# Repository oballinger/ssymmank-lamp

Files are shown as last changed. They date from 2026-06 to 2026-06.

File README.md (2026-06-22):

# Ssymmank lamp

Geometry and 3D-printable parts for the Günter Ssymmank Philharmonie lamp.

The lamp is a **spherical tessellation of regular pentagons, squares and
triangles** — i.e. the **rhombicosidodecahedron** (an Archimedean solid):

| | count |
|---|---|
| pentagons | 12 |
| squares | 30 |
| triangles | 20 |
| vertices | 60 |
| edges | 120 |
| faces | 62 |

Vertex configuration is `3.4.5.4` (triangle, square, pentagon, square meet at
every vertex).

Source / reference exhibition:
https://blog.sbb.berlin/darunter-sieht-man-gut-aus-ausstellung-zu-den-leuchten-guenter-ssymmanks-eroeffnet/

## Layout

Everything is organised **by component**. Each component has its generator code
under `src/<component>/` and its OpenSCAD models under `models/<component>/`.

```
src/
  core/        shared library — the solid's geometry + transform math (imported, not run)
  frame/       build_star.py (printable star/connector decomposition)
  assembly/    build_assembly.py (frame + all 72 mushrooms)
  mockups/     build_mockups.py (the images/ PNG mockups)
models/
  frame/       star · connector · stars_assembly · mate_test · test_edges · stem_fit
    renders/   transient previews / STL exports for the frame (git-ignored)
  mushrooms/   mushroom (+ simple, small/medium/large/xl, small_curved) — hand-written
    renders/   transient previews / STL exports for the mushrooms (git-ignored)
  assembly/    assembly.scad
    renders/   transient previews / STL exports for the assembly (git-ignored)
images/        reference renders (committed)
```

Generators bake all orientation maths (4×4 `multmatrix` transforms) into the
`.scad`, so each `.scad` is just data + tiny modules. The `assembly.scad`
pulls the frame from `../frame/` and the mushroom core from `../mushrooms/`.

### `src/core/` — shared library
| file | what |
|---|---|
| `geometry.py` | single source of truth — vertices, edges, faces of the solid |
| `transforms.py` | the transform helpers (`bar_transforms`, `node_transforms`, …) shared by every generator |

### `src/frame/` → `models/frame/`
| file | what |
|---|---|
| `build_star.py` → `star.scad` + … | the **printable decomposition** (below). `star.scad` is the shared library every other frame model `include`s. |

#### Printable decomposition (generated by `build_star.py`)

The frame is split into just **two printed part types** plus pins/glue. Because
every vertex belongs to exactly one pentagon, and the 120 edges split into 60
pentagon-boundary edges (internal) + 60 inter-pentagon edges (the only links
between pentagons), the partition is clean and complete:

| file | what |
|---|---|
| `star.scad` | **STAR TILE** ×12 (all congruent): hub socket + 5 spokes + 5 corner sockets + 5 boundary bars + 10 connector mortises, fused as one pentagonal wheel (~96 mm across at D=200). |
| `connector.scad` | **CONNECTOR** ×60 (all identical — the solid is Archimedean so every edge is the same length): a flat, shallow-**V** fin (kinked at its middle) with a keyed rectangular tenon at each end. |
| `stars_assembly.scad` | full-frame fit check: 12 coloured tiles + 60 connectors = the complete frame. |
| `mate_test.scad` | two neighbouring tiles + their shared connector, to check the keyed joint seats. |
| `test_edges.scad` | two connectors laid flat, for a quick fit test print. |
| `stem_fit.scad` | a real mushroom stem cone cross-cut in the hub + a corner bore, to verify clearance. |

### `models/mushrooms/` — hand-written mushroom elements
| file | what |
|---|---|
| `mushroom.scad` | detailed mushroom element — curved (spherical) pentagon cap, smooth funnel→cap blend, clipped back ribs. Accurate but heavy to render. |
| `mushroom_simple.scad` | **simplified, fast-loading** mushroom — stretched pentagon cap + cheap fins. Previews in ~0.5 s. Parametric on `STEM_LEN`. Cap curvature `CURVE_RELAX=2.3` makes the cap ~concentric with the lamp centre (radially thin, so shells shingle without intersecting); `DISH_DEPTH=26` funnel. |
| `mushroom_small.scad` · `mushroom_medium.scad` · `mushroom_large.scad` · `mushroom_xl.scad` · `mushroom_xxl.scad` | the simplified mushroom at the **five shell stem lengths** (70 / 84 / 98 / 112 / 126 mm). Each just `include`s the core and overrides `STEM_LEN`; the stem base is identical across all of them. |

### `src/assembly/` → `models/assembly/`
| file | what |
|---|---|
| `assembly.scad` | the full lamp: the frame with all 72 mushrooms, **shingled**. Achieves **zero mushroom–mushroom intersection AND zero light leak** (no straight line-of-sight from the centre escapes between caps) — both verified on the real solids by `_overlap_check.scad`. The 72 sockets are split into **5 radial shells** (stem lengths 70/84/98/112/126) by a 5-colouring of the cap-overlap graph, so every touching pair of caps sits at different radii and overlaps angularly while clearing radially; 5 mushrooms are spun about their radial axis so their stretched arms reach into the square/triangle gaps. `MUSH_SCALE=0.85`, `LAMP_SCALE=3` → 600 mm lamp. Stem tips all seat at the same bore floor, so the frame is unchanged. |
| `_overlap_check.scad` | renders only the 3-D `intersection()` of every close mushroom pair — anything visible (red) is a real physical overlap; an empty render confirms the assembly is collision-free. Regenerate after editing `assembly.scad`. |

All walls/fins are **1 mm thick** (`THICK` in `build_star.py`) — fin thickness,
socket wall, tenon thickness, boss walls. Tuned for **Ultimaker PLA** on a
0.4 mm nozzle: stem slip-fit `FIT_CLR=0.35 mm` radial, tenon press-fit
`KEY_CLR=0.30 mm` (0.15 mm/side).

**Kinked edges.** Every edge bends at its middle so each half leaves its vertex
**perpendicular to the socket axis** (tangent to the sphere) rather than dipping
in along the chord. The kink point `M` is where the sphere's tangent lines at the
two vertices meet — a few mm proud of the chord (≈5 mm for a 45 mm edge) — so the
exits are exactly perpendicular (verified to 0.0000°). `build_star.py` splits each
fused bar into two fins (`a→M`, `M→b`); the separate connectors become shallow
**V**s, and the corner mortise bosses tilt up by the tangent angle (`PHI`) so the
keyed tenons still seat. All geometry (`RAD/HALF/KINK_H/ARM_LEN/PHI`) is derived in
the `.scad` from `EDGE_LEN` and `DIAMETER`.

Print the star **hub-up** (sockets up) with a **brim** for the 1 mm walls.
Footprint ≈ 96 × 100 mm, height ≈ 21 mm — fits any Ultimaker bed.

**Joinery — keyed peg + socket.** With a 1 mm socket wall the mortise can't cut
into the node, so each corner grows a small rectangular **boss into the gap**;
the connector's rectangular tenon (which can't spin) plugs in from the gap side.
Press-fit, with CA for permanence. Joint params
(`KEY_T/KEY_H/KEY_DEPTH/BACK/KEY_CLR`) live at the top of the generated files.

**Socket clearance.** Bars run the full edge length and drive through the node
centre, so each tile's sockets are subtracted from the whole tile **last** (after
the bars union on), plus a straight clearance column out past the fin height —
otherwise the bars refill the bore or lean over the opening. `stem_fit.scad`
cross-sections a real stem cone in the hub/corner bores to verify this.

## Usage

```bash
uv run python src/mockups/build_mockups.py       # regenerate the PNG mockups in images/
uv run python src/frame/build_star.py            # regenerate the printable star + connector parts
uv run python src/assembly/build_assembly.py     # regenerate models/assembly/assembly.scad
```

Open any `.scad` in `models/` and press **F5** (preview) / **F6** (render).
For quick iteration use the `mushroom_simple` family; use `mushroom.scad` only
when you need the final curved cap (it takes much longer to evaluate).

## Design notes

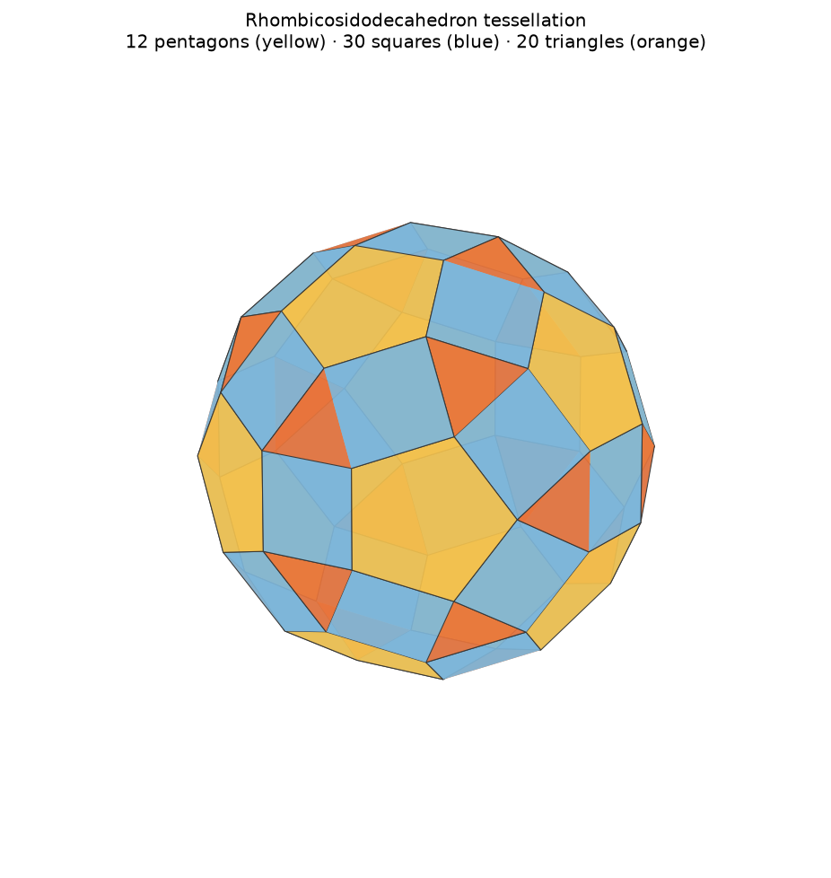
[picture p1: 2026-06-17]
images/mockup_faces.png

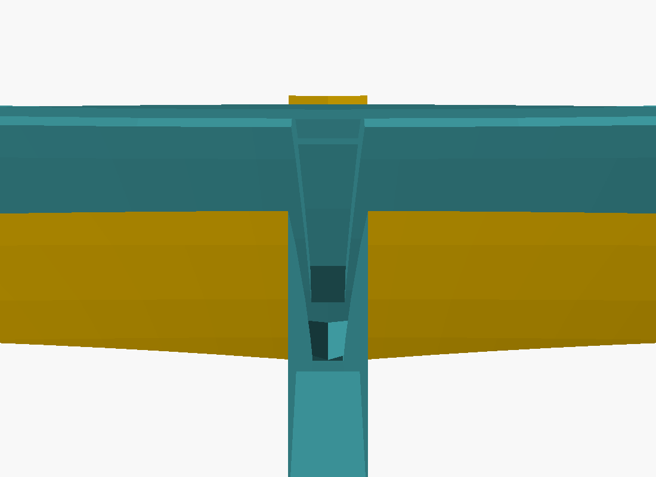
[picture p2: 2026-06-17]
images/mushroom_xsec.png

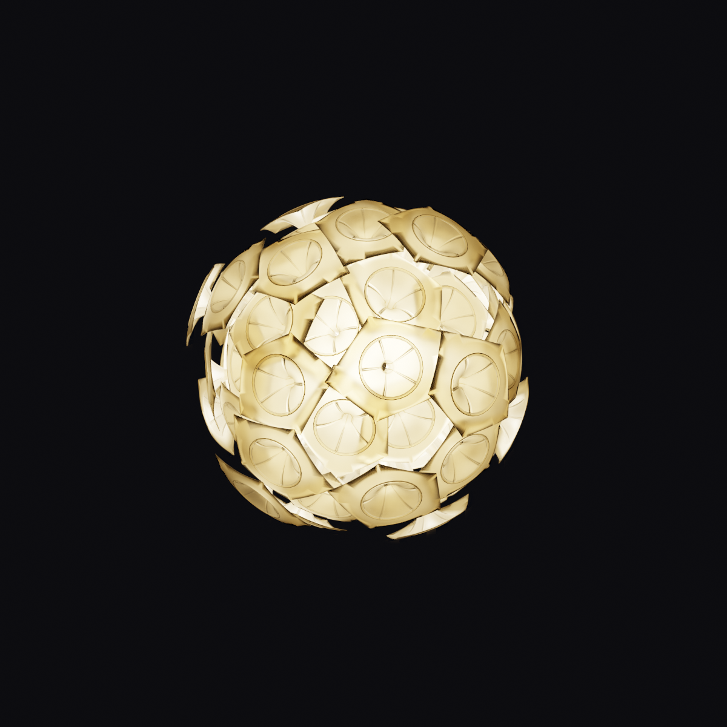
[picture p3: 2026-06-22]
images/lamp_lit.png

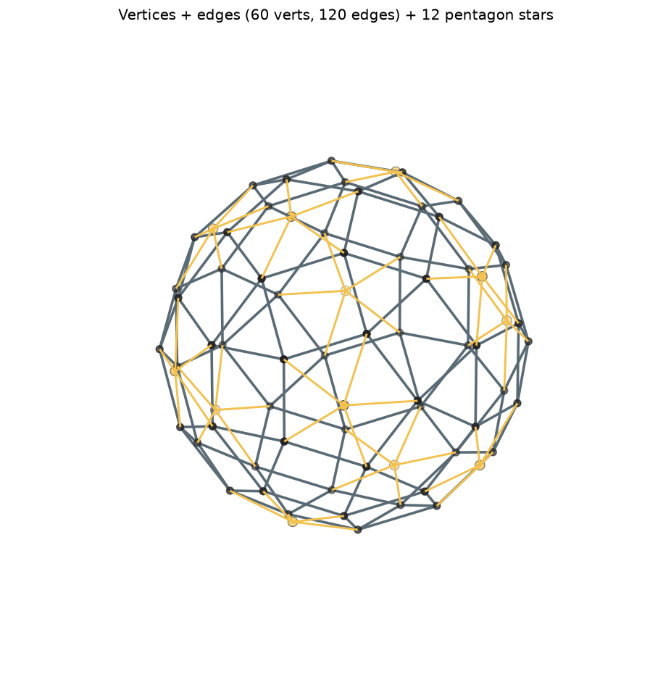
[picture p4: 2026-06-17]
images/mockup_frame.png

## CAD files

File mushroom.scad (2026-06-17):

// Ssymmank mushroom element -- built up step by step.
//
// STEP 1: a simple shallow funnel.
// STEP 2: add a long stem hanging down from the throat.
// STEP 3: make the stem a hollow cone whose bore continues the funnel's.
// STEP 4: rebuild funnel + stem as ONE continuous revolved shell (no gap).
// STEP 5: add a flat pentagon flange on the funnel's open rim
//         (centre stays open so you can still see into the funnel).
// STEP 6: double the pentagon, and stretch two opposing arms (corners) by 2x.
// STEP 7: flat riblike support struts from each pentagon corner down the
//         BACK of the funnel + shaft (nothing on the front/dish side).
// STEP 8: ribs bounded to the vertex/stem and tapered at the corners;
//         rim made flush so pentagon + funnel + stem are one continuous shell.
// STEP 9: curve the pentagon flange backward onto the lamp's circumsphere so
//         tiled mushrooms form a clean sphere, not a faceted solid.
// STEP 10: smooth outer surface -- funnel dish meets the cap tangentially (no
//          hard rim) and the ribs are clipped just under the surface.
// STEP 11: restore a clearly-visible trumpet funnel bowl + conical stem (the
//          tangent dish had flattened them away), keeping the smooth rim/cap.

// ---- parameters -----------------------------------------------------------
LAMP_DIAMETER = 200;  // assembled lamp diameter (mm) -> sets the face curvature

RIM_R    = 40;    // wide rim radius at the top (mm)
THROAT_R = 8;     // narrow throat radius at the bottom (mm)
HEIGHT   = 14;    // funnel height -- shallow (mm)
WALL     = 1.6;   // wall thickness (mm)

STEM_LEN   = 70;  // stem length below the throat (mm) -- long
STEM_TIP_R = 4;   // stem outer radius at the bottom tip (mm)
                  // top radius == THROAT_R so it merges into the funnel

PENT_R   = 68;    // pentagon circumradius, centre -> corner (mm) -- 1.25x of 54
PLATE_T  = 1.6;   // flat pentagon plate thickness (mm)
ARM_STRETCH = 1.25; // radial stretch applied to two opposing arms (corners)
ARM_DROP = 12;    // lower the two long arms by this much in-plane (mm)

RIB_T    = 1.2;   // rib thickness, tangential -- thin, so it reads as 2D
RIB_H    = 4;     // rib depth standing off the back surface (mm)

$fn = 96;

// ---- curvature ------------------------------------------------------------
// The flange is a cap of the circumsphere (radius CIRC_R). The sphere is
// centred on the axis so the flange's inner edge stays at z = HEIGHT (flush
// with the funnel rim); the surface then curves backward toward the arms.
CIRC_R = LAMP_DIAMETER / 2;       // true circumsphere radius (perfect sphere)
CURVE_RELAX = 3.0;                // >1 softens the curve; = 1 is a perfect sphere
CURVE_R = CIRC_R * CURVE_RELAX;   // radius actually used for the flange cap
CAP_ZC = HEIGHT - sqrt(CURVE_R * CURVE_R - (RIM_R - WALL) * (RIM_R - WALL));
function cap_z(rho)     = CAP_ZC + sqrt(CURVE_R * CURVE_R - rho * rho);
function cap_slope(rho) = -rho / sqrt(CURVE_R * CURVE_R - rho * rho);

// ---- funnel dish ----------------------------------------------------------
// A concave trumpet bowl from the throat up to the rim. The rim sits at the
// cap's inner edge height so the funnel and the curved pentagon flange join as
// one continuous shell. The bowl is a smooth circular-arc concave so it reads
// clearly as a funnel and there is no hard crease leaving the throat.
RIM_Z   = cap_z(RIM_R);            // rim height = cap edge (funnel meets flange)
DISH_DEPTH = 34;                   // throat sits this far below the rim (mm)
THROAT_Z   = RIM_Z - DISH_DEPTH;   // throat height
DISH_N  = 28;                      // samples along the dish
// concave arc: quadratic blend giving a steep wall at the throat easing to a
// gentle (near-flat) lip at the rim -- a trumpet, not a straight cone.
function funnel_z(r) =
    let (t = (r - THROAT_R) / (RIM_R - THROAT_R))
        THROAT_Z + DISH_DEPTH * (1 - (1 - t) * (1 - t));
// dish curve sampled (r,z), with the radius pulled in by `off` (0 outer, WALL inner)
function dish_sample(off) =
    [ for (i = [0 : DISH_N])
        let (r = THROAT_R + (RIM_R - THROAT_R) * i / DISH_N)
        [r - off, funnel_z(r)] ];

// ---- body (funnel + stem as one shell) ------------------------------------
// One unbroken (radius, z) profile: stem tip -> throat -> trumpet dish -> rim.
OUTER_PROFILE = concat(
    [[0, -STEM_LEN], [STEM_TIP_R, -STEM_LEN]],
    dish_sample(0),                                  // throat -> rim
    [[0, RIM_Z]]
);
INNER_PROFILE = concat(
    [[0, -STEM_LEN - 1], [STEM_TIP_R - WALL, -STEM_LEN - 1]],
    dish_sample(WALL),                               // inner wall
    [[RIM_R - WALL, RIM_Z + 1], [0, RIM_Z + 1]]
);

module body() {
    rotate_extrude(angle = 360)
        difference() {
            polygon(OUTER_PROFILE);
            polygon(INNER_PROFILE);
        }
}

// ---- pentagon flange on the rim -------------------------------------------
// A flat pentagon at the funnel's open end. A circular hole the size of the
// funnel opening keeps the centre open. Two opposing arms (the left & right
// corners) are stretched radially outward by ARM_STRETCH.
PENT_ANGLES = [90, 162, 234, 306, 18];      // apex up; 162 & 18 are L/R arms
PENT_FACTOR = [1, ARM_STRETCH, 1, 1, ARM_STRETCH];

function pentagon_pts() =
    [ for (i = [0:4])
        let (r = PENT_R * PENT_FACTOR[i], a = PENT_ANGLES[i],
             drop = (PENT_FACTOR[i] > 1) ? ARM_DROP : 0)
        [r * cos(a), r * sin(a) - drop] ];

// The flange is a curved cap of the circumsphere. Built as the top PLATE_T
// slice of a domed solid: take the pentagon prism intersected with a solid
// sphere, then subtract a copy shifted down by PLATE_T. This leaves only the
// top curved slab (no second/bottom cap) and is robust in preview. The hole
// is slightly smaller than the funnel opening so the cap overlaps and fuses
// to the funnel rim (one solid, not two).
FLANGE_HOLE = RIM_R - WALL - 2;   // overlap the rim so the cap fuses to it

module cap_solid() {
    intersection() {
        translate([0, 0, CAP_ZC]) sphere(r = CURVE_R, $fn = 200);
        linear_extrude(height = 4 * CURVE_R, center = true)
            difference() {
                polygon(pentagon_pts());    // pentagon w/ two stretched arms
                circle(r = FLANGE_HOLE);    // funnel opening stays open
            }
    }
}

module pentagon_flange() {
    render()   // force exact (CGAL) eval so the preview shows the whole cap
    difference() {
        cap_solid();
        translate([0, 0, -PLATE_T]) cap_solid();
    }
}

// ---- support struts (flat ribs, back only) --------------------------------
// One thin rib per pentagon corner. It sits entirely on the BACK of the part:
// under the plate, then proud of the funnel's outer surface, then down the
// outside of the shaft. Each rib is thin tangentially (RIB_T) so it reads as
// a flat 2D fin rather than a round rod. Worked out in a meridian frame
// (u = radius, v = height; thin direction = Y) then rotated to the corner's
// azimuth.
// rib tile: flat tangential plate of size s (s -> 0 tapers the rib to a point)
module rib_tile(u, v, s) {
    translate([u, 0, v]) cube([s, RIB_T, s], center = true);
}

module rib(vx, vy) {
    th = atan2(vy, vx);
    cr = sqrt(vx * vx + vy * vy);   // corner radial distance
    o  = RIB_H / 2;                 // push onto the back surface
    TIP = 0.1;                      // taper-to-point size
    // Spine runs along the inner (back) surface: pentagon vertex -> curved cap
    // underside -> smooth dish underside -> down the shaft. Ends taper to a
    // point at the vertex and the stem tip. The whole rib is intersected with
    // the outer envelope below, so it can never break the smooth outer face.
    fs = 4;
    flange = [ for (k = [0 : fs])
                 let (rho = cr + (RIM_R - cr) * k / fs)
                 [rho, cap_z(rho) - PLATE_T, (k == 0) ? TIP : RIB_H] ];
    ds = 6;
    dish = [ for (k = [1 : ds])
               let (r = RIM_R + (THROAT_R - RIM_R) * k / ds)
               [r - WALL - o, funnel_z(r) - WALL, RIB_H] ];
    shaft = [
        [STEM_TIP_R + o, -STEM_LEN + o, RIB_H],   // shaft, above the tip
        [STEM_TIP_R,     -STEM_LEN,     TIP],     // stem tip (point, flush)
    ];
    N = concat(flange, dish, shaft);
    rotate([0, 0, th])
        for (i = [0 : len(N) - 2])
            hull() {
                rib_tile(N[i][0],     N[i][1],     N[i][2]);
                rib_tile(N[i + 1][0], N[i + 1][1], N[i + 1][2]);
            }
}

module ribs() {
    for (p = pentagon_pts()) rib(p[0], p[1]);
}

// open interior (dish + bore): trims rib material off the FRONT / out of dish.
module cavity_solid() {
    rotate_extrude(angle = 360) polygon(INNER_PROFILE);
}
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

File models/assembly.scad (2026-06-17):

// Ssymmank assembly -- full frame + mushrooms on all 12 pentagons.
// Auto-generated by make_assembly.py.
// Per pentagon: centre socket = XL; corners clockwise from the top =
// small, medium, large, medium, large.  72 mushrooms, one per socket.
// Each mushroom's TOP points radially outward from its pentagon centre.
// Mushrooms are scaled by MUSH_SCALE so that no two ever touch.

use <mushroom_simple.scad>;
include <lamp_frame.scad>;

MUSH_SCALE = 0.52;   // <1 shrinks mushrooms so none touch (see make_assembly.py)

// each entry: [ 4x4 placement, stem_length ]
MUSH = [
    [[[-0.80902, -0.58779, 0.00000, 0.00000], [-0.30902, 0.42533, 0.85065, 135.16773], [-0.50000, 0.68819, -0.52573, -83.53825], [0.00000, 0.00000, 0.00000, 1.00000]], 120.96],
    [[[-0.80902, -0.54346, -0.22392, -29.64687], [-0.30902, 0.06919, 0.94854, 125.58617], [-0.50000, 0.83658, -0.22392, -29.64687], [0.00000, 0.00000, 0.00000, 1.00000]], 70.00],
    [[[0.30902, -0.87934, -0.36231, -50.60725], [-0.50000, -0.47427, 0.72462, 101.21451], [-0.80902, -0.04276, -0.58623, -81.88426], [0.00000, 0.00000, 0.00000, 1.00000]], 84.00],
    [[[1.00000, 0.00000, 0.00000, 0.00000], [0.00000, -0.81015, 0.58623, 87.00554], [0.00000, -0.58623, -0.81015, -120.23870], [0.00000, 0.00000, 0.00000, 1.00000]], 100.80],
    [[[0.30902, 0.87934, 0.36231, 50.60725], [0.50000, -0.47427, 0.72462, 101.21451], [0.80902, -0.04276, -0.58623, -81.88426], [0.00000, 0.00000, 0.00000, 1.00000]], 84.00],
    [[[-0.80902, 0.54346, 0.22392, 33.23316], [0.30902, 0.06919, 0.94854, 140.77792], [0.50000, 0.83658, -0.22392, -33.23316], [0.00000, 0.00000, 0.00000, 1.00000]], 100.80],
    [[[0.50000, 0.68819, -0.52573, -83.53825], [-0.80902, 0.58779, 0.00000, 0.00000], [0.30902, 0.42533, 0.85065, 135.16773], [0.00000, 0.00000, 0.00000, 1.00000]], 120.96],
    [[[-0.50000, 0.83658, -0.22392, -29.64687], [-0.80902, -0.54346, -0.22392, -29.64687], [-0.30902, 0.06919, 0.94854, 125.58617], [0.00000, 0.00000, 0.00000, 1.00000]], 70.00],
    [[[-0.80902, -0.04276, -0.58623, -81.88426], [0.30902, -0.87934, -0.36231, -50.60725], [-0.50000, -0.47427, 0.72462, 101.21451], [0.00000, 0.00000, 0.00000, 1.00000]], 84.00],
    [[[0.00000, -0.58623, -0.81015, -120.23870], [1.00000, 0.00000, 0.00000, 0.00000], [0.00000, -0.81015, 0.58623, 87.00554], [0.00000, 0.00000, 0.00000, 1.00000]], 100.80],
    [[[0.80902, -0.04276, -0.58623, -81.88426], [0.30902, 0.87934, 0.36231, 50.60725], [0.50000, -0.47427, 0.72462, 101.21451], [0.00000, 0.00000, 0.00000, 1.00000]], 84.00],
    [[[0.50000, 0.83658, -0.22392, -33.23316], [-0.80902, 0.54346, 0.22392, 33.23316], [0.30902, 0.06919, 0.94854, 140.77792], [0.00000, 0.00000, 0.00000, 1.00000]], 100.80],
    [[[-1.00000, 0.00000, 0.00000, 0.00000], [0.00000, -0.52573, 0.85065, 135.16773], [0.00000, 0.85065, 0.52573, 83.53825], [0.00000, 0.00000, 0.00000, 1.00000]], 120.96],
    [[[-1.00000, 0.00000, 0.00000, 0.00000], [0.00000, -0.81015, 0.58623, 77.61652], [0.00000, 0.58623, 0.81015, 107.26339], [0.00000, 0.00000, 0.00000, 1.00000]], 70.00],
    [[[-0.30902, -0.87934, -0.36231, -50.60725], [0.50000, -0.47427, 0.72462, 101.21451], [-0.80902, 0.04276, 0.58623, 81.88426], [0.00000, 0.00000, 0.00000, 1.00000]], 84.00],
    [[[0.80902, -0.54346, -0.22392, -33.23316], [0.30902, 0.06919, 0.94854, 140.77792], [-0.50000, -0.83658, 0.22392, 33.23316], [0.00000, 0.00000, 0.00000, 1.00000]], 100.80],
    [[[0.80902, 0.54346, 0.22392, 31.27700], [-0.30902, 0.06919, 0.94854, 132.49151], [0.50000, -0.83658, 0.22392, 31.27700], [0.00000, 0.00000, 0.00000, 1.00000]], 84.00],
    [[[-0.30902, 0.87934, 0.36231, 53.77238], [-0.50000, -0.47427, 0.72462, 107.54476], [0.80902, 0.04276, 0.58623, 87.00554], [0.00000, 0.00000, 0.00000, 1.00000]], 100.80],
    [[[-0.00000, 0.85065, 0.52573, 83.53825], [1.00000, 0.00000, 0.00000, 0.00000], [0.00000, 0.52573, -0.85065, -135.16773], [0.00000, 0.00000, 0.00000, 1.00000]], 120.96],
    [[[-0.00000, 0.58623, 0.81015, 107.26339], [1.00000, 0.00000, 0.00000, 0.00000], [0.00000, 0.81015, -0.58623, -77.61652], [0.00000, 0.00000, 0.00000, 1.00000]], 70.00],
    [[[-0.80902, 0.04276, 0.58623, 81.88426], [0.30902, 0.87934, 0.36231, 50.60725], [-0.50000, 0.47427, -0.72462, -101.21451], [0.00000, 0.00000, 0.00000, 1.00000]], 84.00],
    [[[-0.50000, -0.83658, 0.22392, 33.23316], [-0.80902, 0.54346, 0.22392, 33.23316], [-0.30902, -0.06919, -0.94854, -140.77792], [0.00000, 0.00000, 0.00000, 1.00000]], 100.80],
    [[[0.50000, -0.83658, 0.22392, 31.27700], [-0.80902, -0.54346, -0.22392, -31.27700], [0.30902, -0.06919, -0.94854, -132.49151], [0.00000, 0.00000, 0.00000, 1.00000]], 84.00],
    [[[0.80902, 0.04276, 0.58623, 87.00554], [0.30902, -0.87934, -0.36231, -53.77238], [0.50000, 0.47427, -0.72462, -107.54476], [0.00000, 0.00000, 0.00000, 1.00000]], 100.80],
    [[[0.50000, -0.68819, 0.52573, 83.53825], [0.80902, 0.58779, 0.00000, 0.00000], [-0.30902, 0.42533, 0.85065, 135.16773], [0.00000, 0.00000, 0.00000, 1.00000]], 120.96],
    [[[0.50000, -0.83658, 0.22392, 29.64687], [0.80902, 0.54346, 0.22392, 29.64687], [-0.30902, 0.06919, 0.94854, 125.58617], [0.00000, 0.00000, 0.00000, 1.00000]], 70.00],
    [[[0.80902, 0.04276, 0.58623, 81.88426], [-0.30902, 0.87934, 0.36231, 50.60725], [-0.50000, -0.47427, 0.72462, 101.21451], [0.00000, 0.00000, 0.00000, 1.00000]], 84.00],
    [[[0.00000, 0.58623, 0.81015, 120.23870], [-1.00000, 0.00000, 0.00000, 0.00000], [0.00000, -0.81015, 0.58623, 87.00554], [0.00000, 0.00000, 0.00000, 1.00000]], 100.80],
    [[[-0.80902, 0.04276, 0.58623, 81.88426], [-0.30902, -0.87934, -0.36231, -50.60725], [0.50000, -0.47427, 0.72462, 101.21451], [0.00000, 0.00000, 0.00000, 1.00000]], 84.00],
    [[[-0.50000, -0.83658, 0.22392, 33.23316], [0.80902, -0.54346, -0.22392, -33.23316], [0.30902, 0.06919, 0.94854, 140.77792], [0.00000, 0.00000, 0.00000, 1.00000]], 100.80],
    [[[-0.00000, -0.85065, -0.52573, -83.53825], [-1.00000, 0.00000, 0.00000, 0.00000], [0.00000, 0.52573, -0.85065, -135.16773], [0.00000, 0.00000, 0.00000, 1.00000]], 120.96],
    [[[-0.00000, -0.58623, -0.81015, -107.26339], [-1.00000, 0.00000, 0.00000, 0.00000], [0.00000, 0.81015, -0.58623, -77.61652], [0.00000, 0.00000, 0.00000, 1.00000]], 70.00],
    [[[0.80902, -0.04276, -0.58623, -81.88426], [-0.30902, -0.87934, -0.36231, -50.60725], [-0.50000, 0.47427, -0.72462, -101.21451], [0.00000, 0.00000, 0.00000, 1.00000]], 84.00],
    [[[0.50000, 0.83658, -0.22392, -33.23316], [0.80902, -0.54346, -0.22392, -33.23316], [-0.30902, -0.06919, -0.94854, -140.77792], [0.00000, 0.00000, 0.00000, 1.00000]], 100.80],
    [[[-0.50000, 0.83658, -0.22392, -31.27700], [0.80902, 0.54346, 0.22392, 31.27700], [0.30902, -0.06919, -0.94854, -132.49151], [0.00000, 0.00000, 0.00000, 1.00000]], 84.00],
    [[[-0.80902, -0.04276, -0.58623, -87.00554], [-0.30902, 0.87934, 0.36231, 53.77238], [0.50000, 0.47427, -0.72462, -107.54476], [0.00000, 0.00000, 0.00000, 1.00000]], 100.80],
    [[[0.80902, 0.58779, 0.00000, 0.00000], [0.30902, -0.42533, -0.85065, -135.16773], [-0.50000, 0.68819, -0.52573, -83.53825], [0.00000, 0.00000, 0.00000, 1.00000]], 120.96],
    [[[0.80902, 0.54346, 0.22392, 29.64687], [0.30902, -0.06919, -0.94854, -125.58617], [-0.50000, 0.83658, -0.22392, -29.64687], [0.00000, 0.00000, 0.00000, 1.00000]], 70.00],
    [[[-0.30902, 0.87934, 0.36231, 50.60725], [0.50000, 0.47427, -0.72462, -101.21451], [-0.80902, -0.04276, -0.58623, -81.88426], [0.00000, 0.00000, 0.00000, 1.00000]], 84.00],
    [[[-1.00000, 0.00000, 0.00000, 0.00000], [0.00000, 0.81015, -0.58623, -87.00554], [-0.00000, -0.58623, -0.81015, -120.23870], [0.00000, 0.00000, 0.00000, 1.00000]], 100.80],
    [[[-0.30902, -0.87934, -0.36231, -50.60725], [-0.50000, 0.47427, -0.72462, -101.21451], [0.80902, -0.04276, -0.58623, -81.88426], [0.00000, 0.00000, 0.00000, 1.00000]], 84.00],
    [[[0.80902, -0.54346, -0.22392, -33.23316], [-0.30902, -0.06919, -0.94854, -140.77792], [0.50000, 0.83658, -0.22392, -33.23316], [0.00000, 0.00000, 0.00000, 1.00000]], 100.80],
    [[[1.00000, 0.00000, 0.00000, 0.00000], [0.00000, 0.52573, -0.85065, -135.16773], [-0.00000, 0.85065, 0.52573, 83.53825], [0.00000, 0.00000, 0.00000, 1.00000]], 120.96],
    [[[1.00000, 0.00000, 0.00000, 0.00000], [0.00000, 0.81015, -0.58623, -77.61652], [-0.00000, 0.58623, 0.81015, 107.26339], [0.00000, 0.00000, 0.00000, 1.00000]], 70.00],
    [[[0.30902, 0.87934, 0.36231, 50.60725], [-0.50000, 0.47427, -0.72462, -101.21451], [-0.80902, 0.04276, 0.58623, 81.88426], [0.00000, 0.00000, 0.00000, 1.00000]], 84.00],
    [[[-0.80902, 0.54346, 0.22392, 33.23316], [-0.30902, -0.06919, -0.94854, -140.77792], [-0.50000, -0.83658, 0.22392, 33.23316], [0.00000, 0.00000, 0.00000, 1.00000]], 100.80],
    [[[-0.80902, -0.54346, -0.22392, -31.27700], [0.30902, -0.06919, -0.94854, -132.49151], [0.50000, -0.83658, 0.22392, 31.27700], [0.00000, 0.00000, 0.00000, 1.00000]], 84.00],
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

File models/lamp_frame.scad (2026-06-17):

// Ssymmank lamp frame -- rhombicosidodecahedron
// 72 vertex sockets (60 polyhedron vertices + 12 pentagon centres) and
// 180 flat edge bars (120 polyhedron edges + 60 pentagon spokes).
// Auto-generated by make_scad.py.  Each socket points radially outward and
// accepts one mushroom stem.

DIAMETER  = 200.0;   // overall lamp diameter (mm)

// ---- edge bars (flat fins standing radially) ------------------------------
EDGE_H    = 10;       // bar HEIGHT (mm) -- radial; runs the height of the sockets
EDGE_T    = 2;        // bar thickness (mm) -- tangential
                      // (bar length is baked into each transform)

// ---- vertex sockets -------------------------------------------------------
STEM_TIP_R = 4;       // mushroom stem base radius (must match the mushroom)
FIT_CLR    = 0.35;    // radial clearance so the stem slides in
SOCKET_WALL  = 2.2;   // wall around the bore (mm)
SOCKET_H   = EDGE_H;  // socket height = edge height, so edges run its full height
SOCKET_DEPTH = SOCKET_H - 1;   // bore depth (1 mm floor at the inner end)

$fn = 32;

BORE_R_TIP  = STEM_TIP_R + FIT_CLR;        // bore radius at the deep (tip) end
BORE_R_MOUTH = STEM_TIP_R + FIT_CLR + 1.0; // slightly wider at the outer mouth
NODE_R = BORE_R_MOUTH + SOCKET_WALL;       // hub outer radius

// each bar's transform; its x column length IS the bar length
BAR_M = [
    [[0.00000, -0.22975, -0.97325, -97.32490], [0.00000, 0.97325, -0.22975, -22.97529], [44.78380, 0.00000, 0.00000, 0.00000], [0.00000, 0.00000, 0.00000, 1.00000]],
    [[0.00000, 0.22975, -0.97325, -97.32490], [44.78380, 0.00000, 0.00000, 0.00000], [0.00000, -0.97325, -0.22975, -22.97529], [0.00000, 0.00000, 0.00000, 1.00000]],
    [[13.83895, 0.30075, -0.90225, -90.22514], [22.39190, -0.85837, -0.11488, -11.48765], [-36.23085, -0.41563, -0.41563, -41.56269], [0.00000, 0.00000, 0.00000, 1.00000]],
    [[22.39190, -0.11488, -0.85837, -85.83725], [-36.23085, -0.41563, -0.41563, -41.56269], [-13.83895, 0.90225, -0.30075, -30.07505], [0.00000, 0.00000, 0.00000, 1.00000]],
    [[0.00000, -0.22975, -0.97325, -97.32490], [44.78380, 0.00000, 0.00000, 0.00000], [0.00000, -0.97325, 0.22975, 22.97529], [0.00000, 0.00000, 0.00000, 1.00000]],
    [[13.83895, -0.30075, -0.90225, -90.22514], [22.39190, 0.85837, -0.11488, -11.48765], [36.23085, -0.41563, 0.41563, 41.56269], [0.00000, 0.00000, 0.00000, 1.00000]],
    [[22.39190, 0.11488, -0.85837, -85.83725], [-36.23085, 0.41563, -0.41563, -41.56269], [13.83895, 0.90225, 0.30075, 30.07505], [0.00000, 0.00000, 0.00000, 1.00000]],
    [[0.00000, 0.22975, -0.97325, -97.32490], [0.00000, 0.97325, 0.22975, 22.97529], [44.78380, -0.00000, 0.00000, 0.00000], [0.00000, 0.00000, 0.00000, 1.00000]],
    [[13.83895, -0.30075, -0.90225, -90.22514], [-22.39190, -0.85837, 0.11488, 11.48765], [-36.23085, 0.41563, -0.41563, -41.56269], [0.00000, 0.00000, 0.00000, 1.00000]],
    [[22.39190, 0.11488, -0.85837, -85.83725], [36.23085, -0.41563, 0.41563, 41.56269], [-13.83895, -0.90225, -0.30075, -30.07505], [0.00000, 0.00000, 0.00000, 1.00000]],
    [[13.83895, 0.30075, -0.90225, -90.22514], [-22.39190, 0.85837, 0.11488, 11.48765], [36.23085, 0.41563, 0.41563, 41.56269], [0.00000, 0.00000, 0.00000, 1.00000]],
    [[22.39190, -0.11488, -0.85837, -85.83725], [36.23085, 0.41563, 0.41563, 41.56269], [13.83895, -0.90225, 0.30075, 30.07505], [0.00000, 0.00000, 0.00000, 1.00000]],
    [[22.39190, -0.48662, -0.71638, -71.63774], [-36.23085, -0.55762, -0.18587, -18.58740], [-13.83895, 0.67250, -0.67250, -67.24985], [0.00000, 0.00000, 0.00000, 1.00000]],
    [[22.39190, 0.48662, -0.71638, -71.63774], [36.23085, -0.55762, 0.18587, 18.58740], [-13.83895, -0.67250, -0.67250, -67.24985], [0.00000, 0.00000, 0.00000, 1.00000]],
    [[22.39190, 0.48662, -0.71638, -71.63774], [-36.23085, 0.55762, -0.18587, -18.58740], [13.83895, 0.67250, 0.67250, 67.24985], [0.00000, 0.00000, 0.00000, 1.00000]],
    [[22.39190, -0.48662, -0.71638, -71.63774], [36.23085, 0.55762, 0.18587, 18.58740], [13.83895, -0.67250, 0.67250, 67.24985], [0.00000, 0.00000, 0.00000, 1.00000]],
    [[13.83895, -0.67250, -0.67250, -67.24985], [-22.39190, 0.48662, -0.71638, -71.63774], [36.23085, 0.55762, -0.18587, -18.58740], [0.00000, 0.00000, 0.00000, 1.00000]],
    [[13.83895, 0.67250, -0.67250, -67.24985], [22.39190, -0.71638, -0.48662, -48.66245], [-36.23085, -0.18587, -0.55762, -55.76221], [0.00000, 0.00000, 0.00000, 1.00000]],
    [[36.23085, 0.18587, -0.55762, -55.76221], [-13.83895, -0.67250, -0.67250, -67.24985], [-22.39190, 0.71638, -0.48662, -48.66245], [0.00000, 0.00000, 0.00000, 1.00000]],
    [[13.83895, 0.67250, -0.67250, -67.24985], [-22.39190, -0.48662, -0.71638, -71.63774], [-36.23085, 0.55762, 0.18587, 18.58740], [0.00000, 0.00000, 0.00000, 1.00000]],
    [[13.83895, -0.67250, -0.67250, -67.24985], [22.39190, 0.71638, -0.48662, -48.66245], [36.23085, -0.18587, 0.55762, 55.76221], [0.00000, 0.00000, 0.00000, 1.00000]],
    [[36.23085, -0.18587, -0.55762, -55.76221], [-13.83895, 0.67250, -0.67250, -67.24985], [22.39190, 0.71638, 0.48662, 48.66245], [0.00000, 0.00000, 0.00000, 1.00000]],
    [[13.83895, -0.67250, -0.67250, -67.24985], [-22.39190, -0.71638, 0.48662, 48.66245], [-36.23085, 0.18587, -0.55762, -55.76221], [0.00000, 0.00000, 0.00000, 1.00000]],
    [[13.83895, 0.67250, -0.67250, -67.24985], [22.39190, 0.48662, 0.71638, 71.63774], [36.23085, -0.55762, -0.18587, -18.58740], [0.00000, 0.00000, 0.00000, 1.00000]],
    [[36.23085, -0.18587, -0.55762, -55.76221], [13.83895, -0.67250, 0.67250, 67.24985], [-22.39190, -0.71638, -0.48662, -48.66245], [0.00000, 0.00000, 0.00000, 1.00000]],
    [[13.83895, 0.67250, -0.67250, -67.24985], [-22.39190, 0.71638, 0.48662, 48.66245], [36.23085, 0.18587, 0.55762, 55.76221], [0.00000, 0.00000, 0.00000, 1.00000]],
    [[13.83895, -0.67250, -0.67250, -67.24985], [22.39190, -0.48662, 0.71638, 71.63774], [-36.23085, -0.55762, 0.18587, 18.58740], [0.00000, 0.00000, 0.00000, 1.00000]],
    [[36.23085, 0.18587, -0.55762, -55.76221], [13.83895, 0.67250, 0.67250, 67.24985], [22.39190, -0.71638, 0.48662, 48.66245], [0.00000, 0.00000, 0.00000, 1.00000]],
    [[36.23085, 0.41563, -0.41563, -41.56269], [-13.83895, -0.30075, -0.90225, -90.22514], [-22.39190, 0.85837, -0.11488, -11.48765], [0.00000, 0.00000, 0.00000, 1.00000]],
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

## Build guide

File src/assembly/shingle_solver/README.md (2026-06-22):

# shingle_solver

Derives the **shingled** mushroom layout in `models/assembly/assembly.scad`:
**zero mushroom-mushroom intersection AND zero light leak** (no straight
line-of-sight from the centre escapes between caps). Intersections are measured
*exactly* on the real OpenSCAD solids (`intersection()` → non-empty STL = overlap);
light leak by ray-casting from the origin against the cap surfaces.

## The idea

The two goals fight: full angular coverage forces caps to overlap, and rigid
overlapping caps intersect. The resolution is **radial shingling** plus three
shape tweaks (all kept "pentagonal, slightly curved", stretched arms retained):

1. **Concentric caps** — `CURVE_RELAX=2.3` makes each cap a patch ~concentric
   with the lamp centre, so it is *radially thin* and slides past other shells'
   caps instead of doming into them.
2. **5 radial shells** (stems 70/84/98/112/126) assigned by a **proper
   5-colouring of the cap-overlap graph at the coverage scale** — so no two
   *touching* caps share a shell. Same-shell caps never overlap; cross-shell
   pairs are at different radii and shingle. (Colouring at a *sparse* scale was
   the original bug — it isn't proper once caps grow to cover.)
3. **Shallow funnel** (`DISH_DEPTH=26`) so an outer shell's funnel clears the
   next-inner shell's caps.
4. **Per-mushroom azimuth** — 5 mushrooms spun about their radial axis so their
   stretched arms reach into the square/triangle gaps (empty) instead of
   skewering a neighbour's stem. Stored in `theta_d26.json`.

Stem tips all seat at the same bore floor, so the **frame is unchanged**.

## Files

| file | what |
|---|---|
| `analyze.py` | mushroom geometry reconstruction + ray-cast light-leak (coverage) |
| `opt.py` | fast evaluator (KD-tree clearance, fibonacci-sphere leak) used by `color` |
| `color.py` | cap-overlap adjacency graph + backtracking k-colouring |
| `color3.py` | per-variant mushroom STL render + **OpenSCAD intersection oracle** + leak |
| `orient.py` | per-mushroom azimuth optimiser (greedy, oracle-driven) → `theta_d26.json` |
| `build.py` | **regenerates** `models/assembly/assembly.scad` + `_overlap_check.scad` |
| `theta_d26.json` | the solved per-mushroom azimuths (5 non-zero) |

## Run

```bash
# regenerate the assembly from the solved orientations
python3 src/assembly/shingle_solver/build.py

# re-solve the orientations from scratch (overwrites theta on disk if you wire it)
python3 src/assembly/shingle_solver/orient.py
```

Needs `numpy`, `scipy`, and OpenSCAD (set `$OPENSCAD` if not at the macOS
default `/Applications/OpenSCAD.app/...`). The leak metric (rays) is reliable; a
point-cloud nearest-distance metric is NOT (it can't see one shell poking
*through* another) — only the OpenSCAD `intersection()` oracle is trusted for
collisions.

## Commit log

2026-06-17 Rhombicosidodecahedron mockup of the Ssymmank lamp
    12 pentagons / 30 squares / 20 triangles (60 verts, 120 edges).
    - geometry.py: vertices/edges/faces from convex hull
    - mockup.py: coloured tessellation + plain vertices+edges wireframe
    - make_scad.py -> lamp_frame.scad: OpenSCAD strut frame
    [lamp_frame.scad]
2026-06-17 Add star hub at the centre of each pentagon
    12 star hubs (one per pentagon), each with 5 spokes to the pentagon
    corners. Added to geometry.pentagon_stars(), the frame mockup, and the
    OpenSCAD model (SPOKE_R / STAR_R parameters).
    [lamp_frame.scad]
2026-06-17 Push pentagon stars out to the circumsphere
    pentagon_stars() now takes a bulge factor (default 1.0) projecting each
    star centre radially onto the circumsphere, doming the pentagons so the
    frame reads as spherical rather than recessed.
    [lamp_frame.scad]
2026-06-17 Add parametric mushroom element (funnel + stem + pentagon + back ribs)
    mushroom.scad, built up step by step: shallow funnel -> long hollow
    conical stem -> single continuous revolved shell -> stretched/dropped
    flat pentagon flange -> tapered flat back-ribs bounded to the vertices
    and stem tip. Flush rim so pentagon + funnel + stem are one shell.
    Exports as a valid 2-manifold solid (Simple: yes).
    [mushroom.scad]
2026-06-17 Curve the pentagon flange onto the lamp circumsphere
    The flange is now a spherical cap of the circumsphere (radius driven by
    LAMP_DIAMETER), curving backward toward the arms so tiled mushrooms form
    a clean sphere rather than a faceted solid. Inner edge stays flush with
    the funnel rim; back-ribs follow the curved underside. Still Simple: yes.
    [mushroom.scad]
2026-06-17 Soften flange curvature and fix preview/robustness
    - CURVE_RELAX 1.8 -> 3.0 (gentler backward curve)
    - rebuild cap as top slice of a domed solid (no stray bottom cap),
    overlapping the funnel rim so it fuses into one body
    - wrap flange in render() to fix OpenCSG preview dropping half the cap
    Verified: exported STL is a single watertight solid.
    [mushroom.scad]
2026-06-17 Smooth outer surface: tangent funnel-to-cap, no hard rim, clipped ribs
    - funnel dish is now a Hermite curve meeting the cap tangentially at the
    rim (matched height + slope) so there is no hard rim; outer surface
    flows smoothly from bowl into pentagon
    - DISH_DEPTH restores bowl depth lost to the smooth blend
    - ribs follow the new dish underside and are intersected with the outer
    envelope so they never poke through the smooth outer face
    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
    [mushroom.scad]
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2026-06-17 Reorganize repo into src/models/images and add fast simplified mushroom
    Layout: Python tools -> src/, OpenSCAD -> models/, committed renders ->
    images/, transient output -> git-ignored renders/. Scripts now write to the
    new dirs via paths relative to the repo root.
    mushroom.scad (detailed): drop the top-level and flange render() calls and
    rebuild the cap as a concentric spherical shell, and lower facet counts -- the
    forced CGAL on every auto-reload was what made previews take minutes. Geometry
    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
    [lamp_frame.scad, mushroom.scad, mushroom_large.scad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]
2026-06-17 Rebuild lamp frame: outward mushroom sockets + flat edge bars
    Vertices are now cylindrical sockets (one per vertex, pointing radially
    outward) with a tapered bore matched to the mushroom stem base (STEM_TIP_R),
    so each vertex receives one mushroom pointing outward. Edges are flat bars
    (2 mm thick x 10 mm wide) lying tangent to the sphere. Orientation transforms
    are computed in numpy and baked into the .scad as multmatrix matrices; the
    star hubs/spokes are gone.
    [lamp_frame.scad]
2026-06-17 Frame: pivot edge bars to radial fins, match socket height to edge height
    Edge bars are rotated 90 deg about their length so the 10 mm dimension now
    runs radially (a standing fin) instead of tangentially; thickness (2 mm) is
    tangential. Sockets are centred on the vertex with height = edge height, so
    the edges run the full height of the sockets. Bars sit on the sphere radius,
    level with the sockets.
    [lamp_frame.scad]
2026-06-17 Frame: restore pentagon-centre sockets + spokes (72 sockets, 180 bars)
    The 12 pentagon-centre hubs and their 5 spokes were dropped in the socket
    rebuild; bring them back as full sockets (projected onto the circumsphere, so
    each pentagon centre also takes a mushroom) joined to their corners by spoke
    bars. Generalized the bar generator to bake length into each transform so it
    handles the spokes' different length alongside the equal polyhedron edges.
    [lamp_frame.scad]
2026-06-17 Add oriented 5-mushroom assembly on one pentagon
    Refactor mushroom_simple into a reusable module mushroom(stem_len) (profiles
    are now functions of stem length); size variants still work via STEM_LEN
    override. Add make_assembly.py + assembly_pentagon.scad: places a mushroom on
    each of one pentagon's 5 corners, oriented so the mushroom top (the pentagon
    apex, above the two long arms) points radially outward from the pentagon
    centre, stem plugged into the outward-pointing socket.
    [assembly_pentagon.scad, mushroom_simple.scad]
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2026-06-17 Assembly: scale mushrooms so none touch (MUSH_SCALE)
    Measured collisions with a nesting-aware surface model (caps nesting into
    neighbours' open bowls count as clear). Findings:
    - full-size mushrooms: 34 real contacts; caps (68mm) are far wider than socket
    spacing, so no height layout reaches zero.
    - counter-intuitively a wider stem range / near-stemless S makes it WORSE
    (170+): a cap pulled inward subtends a larger angle and gets pierced by
    neighbours' stems. Cap-size-vs-frame is the real lever, not stem length.
    - zero-contact threshold: cap circumradius ~37mm staggered / ~34mm uniform.
    Implemented MUSH_SCALE=0.52 (cap ~35mm), staggered layout kept -> 0 touching
    pairs at >=2mm clearanc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
    [assembly.scad, star.scad, stars_assembly.scad]
2026-06-17 Simplified mushroom: add backward curvature cheaply (CURVE_CAP)
    Port mushroom.scad's spherical-cap curvature to mushroom_simple as a flat
    pentagon prism intersected with a concentric uniform-thickness shell -- no
    render(), so it stays a fast OpenCSG preview. The earlier slowness was the
    forced CGAL, not the geometry: single mushroom still ~0.44s, full 72-mushroom
    assembly ~4.4s. CURVE_CAP=false reverts to the flat cap.
    [mushroom_simple.scad]
2026-06-17 Fix curved cap: clip to upper hemisphere (kill antipodal second pentagon)
    The concentric shell is a full sphere, so intersecting it with the tall
    pentagon prism produced TWO caps -- the intended top cap and the antipodal
    bottom cap (a second curved pentagon-with-hole floating far below / through the
    lamp centre). Add an upper-half clip (z >= CAP_ZC) so only the top cap
    survives. Applied to both mushroom_simple.scad and mushroom.scad.
    [mushroom.scad, mushroom_simple.scad]
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2026-06-17 Thin everything to 0.8mm (PLA, 0.4mm nozzle = 2 perimeters)
    WALL 1.6->0.8 (funnel/stem), RIB_T 1.2->0.8; petals already 0.8. Thinning the
    shell broke fusion (cap + ribs detached from the funnel as a separate body),
    so weld them robustly: RIB_BITE sinks each rib through the wall into the bore,
    and CAP_OVERLAP grown to 3mm so the curved cap overlaps the funnel rim with
    margin. Large production STL re-exported: one body, watertight, 0 holes /
    0 non-manifold edges, 12.7 cm^3.
    [mushroom_simple.scad]
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2026-06-22 Loosen keyed joint: KEY_CLR 0.30 -> 0.50 for Tough PLA
    0.30mm split over two mortise faces was ~0.15mm/side -- too tight on the
    UM3 with Tough PLA. 0.50 gives ~0.25mm/side.
    [star.scad]
2026-06-22 Shingled assembly: zero intersections + zero light leak (verified)
    Solve the assembly so no two mushrooms intersect AND no straight line-of-sight
    from the centre escapes between caps. Both verified on the real OpenSCAD solids
    (intersection() oracle) and by ray-casting; stretched pentagon caps kept.
    - mushroom_simple: CURVE_RELAX 3.0->2.3 (caps ~concentric with lamp centre ->
    radially thin), DISH_DEPTH 34->26 (funnel clears inner shells)
    - assembly.scad: 72 mushrooms in 5 radial SHELLS (stems 70/84/98/112/126) by a
    5-colouring of the cap-overlap graph; 5 mushrooms spun so stretched arms reach
    into the square/triangle gaps. LAMP_SCALE 1.3797 -> true 600mm lamp. Frame
    unchanged (stem t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
    [_overlap_check.scad, lamp_frame.scad, mushroom_large.scad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]
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
